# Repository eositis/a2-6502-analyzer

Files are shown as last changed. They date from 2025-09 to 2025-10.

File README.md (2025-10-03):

# a2-6502-analyzer
The A2-6502 is an adapter allowing [Dr Gusman's LogicAnalyzer](https://github.com/gusmanb/logicanalyzer) to capture all 6502 signal pins on an Apple II. This adapter is spefically designed for the Apple IIc, but work equally well in the Apple IIe. It will work in the older Apple II and II+, however extra spacers are required, as the expansion slots get in the way.

In the Apple IIc, the adapter fits into the motherboard's CPU socket, even with the motherboard still in the case. No other components are obstructed, giving the user complete access to all available signals on the board. In an Apple IIe, the adapter's layout also allows access to all signals on the system. It does however block the use of slots 3 and 4.



The adapter board maps the Apple IIc 6502 signals to specific ports on the LogicAnalyzer pair. An additional 16 ports are available on an expansion header, allowing the user to not only capture cpu specific signals, but to also reach out to additional areas of the system to gather related information.

Dr Gusman's 6.5 release is recommended for this deployment. At this time, it is still in beta. This release provides profile support, and allows the user to import a port assignment set when using the a2-6502 adapter. A basic profile for this board is available [here](https://github.com/eositis/a2-6502-analyzer/tree/main/Gusmans-LogicAnalyzer).
1. profiles.json
   - MacOS and Linux users copy the file to $HOME/Library/Application Support/LogicAnalyzer
   - Windoze users copy the file to %userprofile%/appdata/roaming/logicanalyzer
   - if you already have a pofile created, you will need to copy the relevant data into your existing profile

## Initial Setup
1) Install firmware to LogicAnalyzer
2) Install two LogicAnalyzer boards to the adapter with the component side facing the cpu
3) Using three DuPont cables, connect the linking headers between the two boards. Does not matter which ports combination is used, as long as top is to top, middle to middle and bottom to bottom.
   - LogicAnalyzers purchased from me will be configured to snap together, eliminating this step.
4) Remve the cpu from the system board, and install it in the provided space on the adapter board. Be sure to maintain the correct notch orientation.
   - Optionally, install a spare CPU in the adapter board, leaving it there permanently. Set aside the system's CPU for the duration of the tests.
6) Carefully plug the adapter board into the cpu socket on the mother board - once again, take care to maintain correct notch orientation. Make sure the adapter is fully seated in the socket.
   - Some older sockets may not have sufficiently large holes for the logic analyzer's pins. If this is the case, install a doublewipe cpu socket to the motherboard and plug the logic analyzer adapter board into the doublewipe socket.
8) Download and configure the LogicAnalyzer software
   - Stable release here: https://github.com/gusmanb/logicanalyzer/releases
   - 6.5 beta realease information is here: https://github.com/gusmanb/logicanalyzer/discussions/277
10) follow install and operation guidelines in the [LogicAnalyzer wiki](https://github.com/gusmanb/logicanalyzer/wiki/06---The-LogicAnalyzer-program)

### Setup LogicAnalyzer boards using USB
1) Two USB cables will be needed
2) On the adapter board, set the jumper/switch to USB mode.
   - WiFi mode should only be used when the LogicAnalyzer has been configured for Network operation running in full wireless mode.
3) On each LogicAnalyzer board is a switch to set reference voltage
   - Typically should be set to EXT mode. This will use the Apple II system's 5v rail as a reference
   - The 5V reference can also be used. This mode can be used if testing Apple II power-on procedures. Testers have suggested that the LogicAnalyzer should start up faster than the Apple II, however this has not been confirmed.
4) Install firmware
   - extract the firmware appropriate for the Pico board installed on the LogicAnalyzers. This firmware is a part of the comprehensive download performed in an earlier step
   - each Pico board has a small reset button. Hold down this button wile plugging in one of the USB cables. Repeat for the other board.
   - on your computer, two new USB volumes will appear. Copy the appropriate firmware to the storage volume. Immediately once the copy completes, the volume will disconnect from your computer and the LogicAnalyzer will reset and boot the new firmware.
5) Configure for use
   - Start the LogicAnalyzer software
   - connect USB cables to each of the logic analyzers
   - Configure a MultiDevice scanner
   - Click 'open device'
   - Select one of the LogicAnalyzer boards as master
   - Add the second one as slave, Accept
   - Execute a data capture from an Apple II machine, do add signals via the J3 port at this time
   - Channels up to  32 should have data. Channels 33-48 should be blank lines. If this is not the case, close the device and recreate it, placing the other LogicAnalyzer as master.
   - From the profiles menu, select the previously imported Apple II profile
6) Congratulations! Setup is complete!

## Channel assignments
| J1-Analyzer1 | Signal | Pin | J2-Analyzer2 | Signal |
|---:|---|---|---:|---|
| CH-1 | RDY | 1 | CH-25 | A8 |
| CH-2 | IRQ\ | 2 | CH-26 | A9 |
| CH-3 | NMI\ | 3 | CH-27 | A10 |
| CH-4 | R/W\ | 4 | CH-28 | A11 |
| CH-5 | PHASE0 | 5 | CH-29 | A12 |
| CH-6 | RES\ | 6 | CH-30 | A13 |
| CH-7 | D0 | 7 | CH-31 | A14 |
| CH-8 | D1 | 8 | CH-32 | A15 |
| CH-9 | D2 | 9 | CH-33 | J3-1 |
| CH-10 | D3 | 10 | CH-34 | J3-2 |
| CH-11 | D4 | 11 | CH-35 | J3-3 |
| CH-12 | D5 | 12 | CH-36 | J3-4 |
| CH-13 | D6 | 21 | CH-37 | J3-5 |
| CH-14 | D7 | 22 | CH-38 | J3-6 |
| CH-15 | A1 | 23 | CH-39 | J3-7 |
| CH-16 | A2 | 24 | CH-40 | J3-8 |
| CH-17 | A3 | 25 | CH-41 | J3-9 |
| CH-18 | A4 | 26 | CH-42 | J3-10 |
| CH-19 | A5 | 27 | CH-43 | J3-11 |
| CH-20 | A6 | 28 | CH-44 | J3-12 |
| CH-21 | A7 | 29 | CH-45 | J3-13 |
| CH-22 | A8 | 30 | CH-46 | J3-14 |
| CH-23 | Phase1 | 32 | CH-47 | J3-15 |
| CH-24 | SYNC | 32 | CH-48 | J3-16 |

## J3 header pin assignments
The Opt X.nn signals are routed to the J3 breakout header. The user can use standard DuPont cables and clips to reach out to other parts of the system for additional data.
The J3 header signals are ordered as follows:

| PIN-1 | PIN-3 | PIN-5 | PIN-7 | PIN-9 | PIN-11 | PIN-13 | PIN-15 |
|:-----:|:-----:|:-----:|:-----:|:-----:|:-----:|:-----:|:-----:|
| CH-33 | CH-35 | CH-37 | CH-39 | CH-41 | CH-43 | CH-45 | CH-47 |
| CH-34 | CH-36 | CH-38 | CH-40 | CH-42 | CH-44 | CH-46 | CH-48 |
| PIN-2 | PIN-4 | PIN-6 | PIN-8 | PIN-10 | PIN-12 | PIN-14 | PIN-16 |

## Schematics
Production v1.5 schematic: https://github.com/eositis/a2-6502-analyzer/blob/main/kicad/v1.5/6502-interposer-schematic-1_5.pdf

### Board View
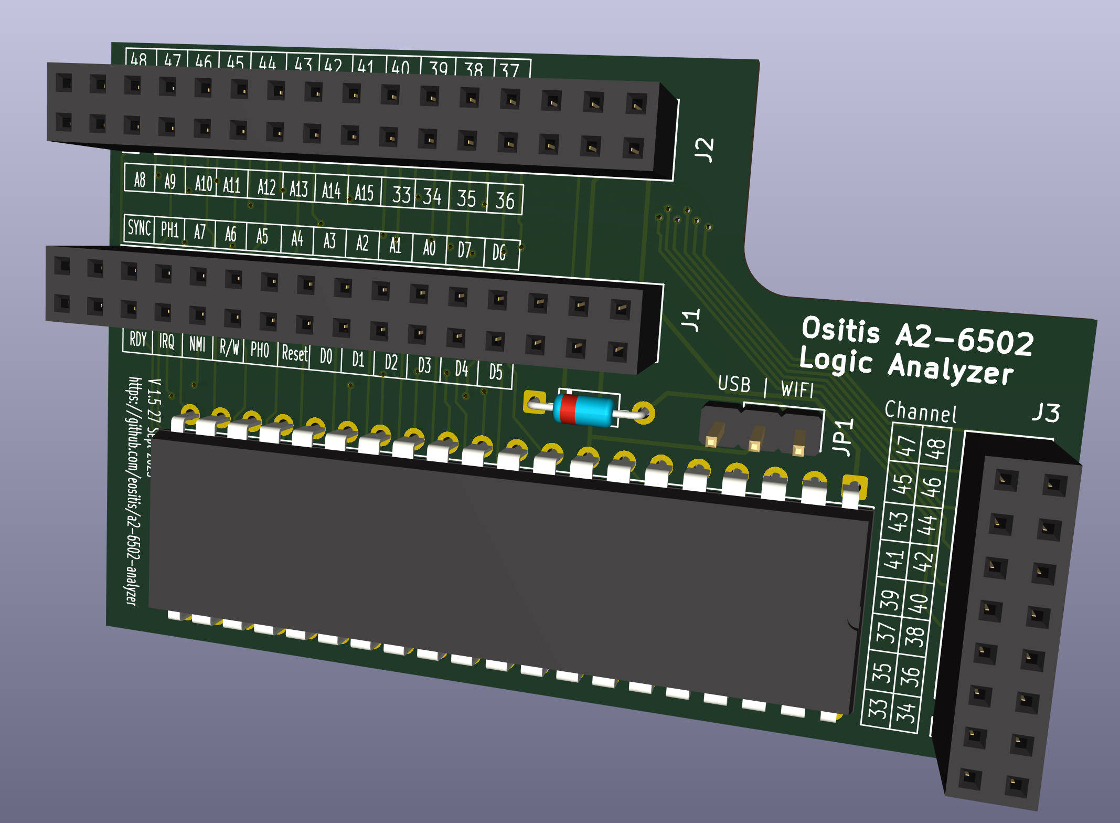
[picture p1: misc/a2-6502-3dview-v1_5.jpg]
a2-6502-v1 5


### Ready to collect data
a2-6502-action-v1_4

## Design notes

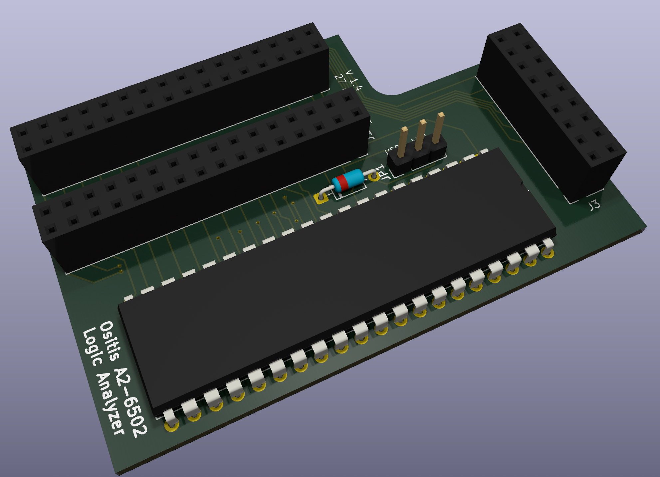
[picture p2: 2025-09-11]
a2-6502v14.jpg

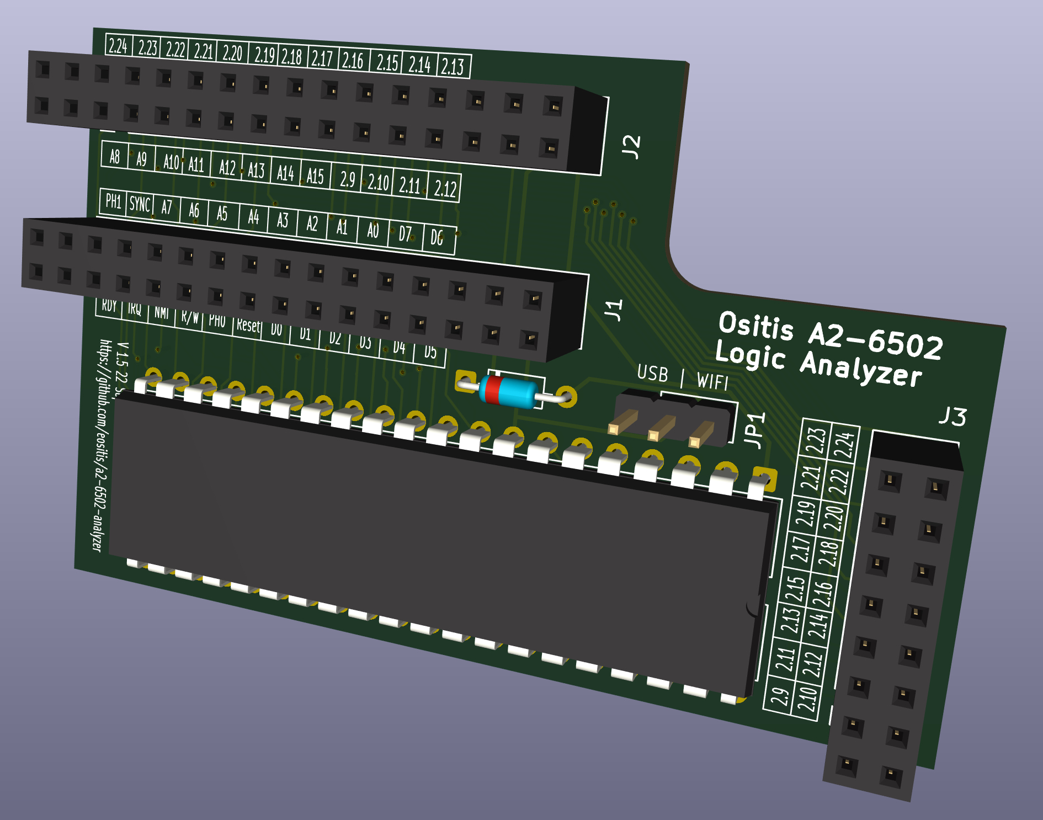
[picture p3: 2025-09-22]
a2-6502-v1.5.jpg

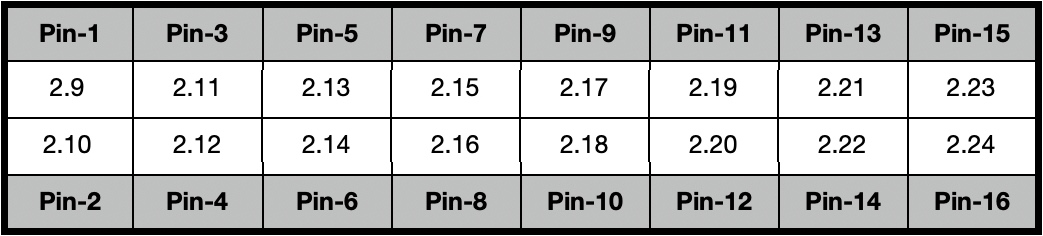
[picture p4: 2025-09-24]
misc/a2-6502-J3header.jpg

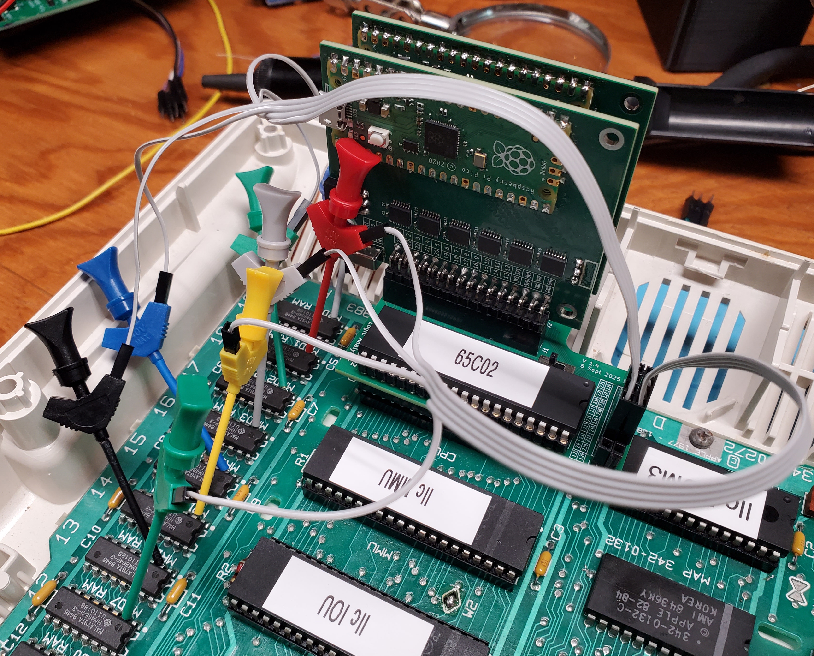
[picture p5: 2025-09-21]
misc/a2-6502-action-v1_4.jpg

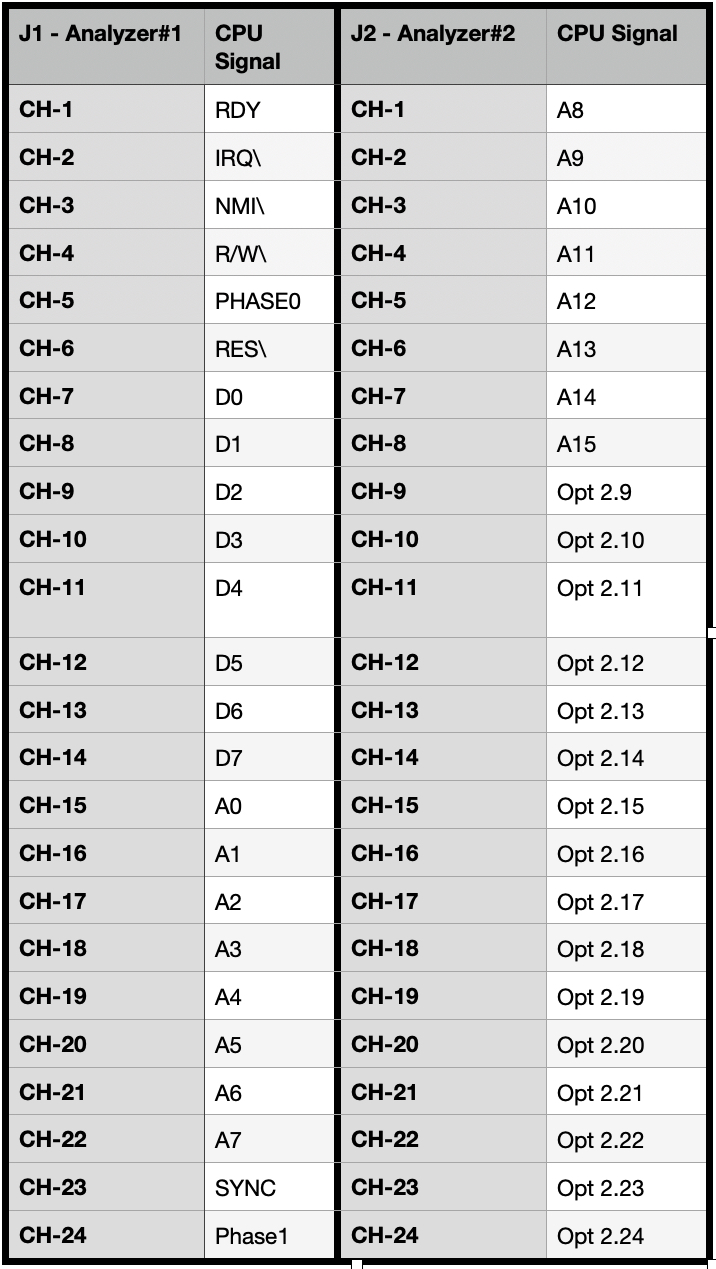
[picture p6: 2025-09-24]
misc/signal-assignments.jpg

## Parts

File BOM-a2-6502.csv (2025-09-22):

Table 1
Designator | Qty | Description | Part number | Mfg | Digikey Part Number | Notes
J1,J2 | 2 | CONN HDR 36POS 0.1 TIN PCB | PPTC182LFBN-RC | Sullins Connector Solutions | S7086-ND
J3 | 1 | CONN HDR 16POS 0.1 TIN PCB | PPTC082LFBN-RC | Sullins Connector Solutions | S7076-ND
JP1 | 1 | CONN HEADER VERT 3POS 2.54MM | HTSW-103-07-T-S | Samtec Inc. | SAM9525-ND
JP1 | 1 | CONN JUMPER SHORTING GOLD FLASH | SPC02SYAN | Sullins Connector Solutions | S9001-ND
U1 | 1 | CONN IC DIP SOCKET 40POS | AR 40-HZL-TT | Assmann WSW | 123-AR40-HZL-TT-ND
U1 | 1 | CONN RCPT 20POS 0.1 GOLD PCB | 324-43-120-41-002000 | Mill-Max Manufacturing Corp. | 324-43-120-41-002000-ND | alternate 11.75mm item from https://www.aliexpress.us/item/3256803132204291.html
D1 | 1 | DIODE STANDARD 100V 200MA DO35 | 1N4148 | onsemi | 1N4148FS-ND

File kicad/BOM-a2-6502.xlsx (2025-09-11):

Table 1
Designator | Qty | Description | Part number | Mfg | Digikey Part Number | Notes
J1,J2 | 2 | CONN HDR 36POS 0.1 TIN PCB | PPTC182LFBN-RC (https://www.digikey.com/en/products/detail/sullins-connector-solutions/PPTC182LFBN-RC/810224) | Sullins Connector Solutions | S7086-ND
J3 | 1 | CONN HDR 18POS 0.1 TIN PCB | PPTC092LFBN-RC (https://www.digikey.com/en/products/detail/sullins-connector-solutions/PPTC092LFBN-RC/810215) | Sullins Connector Solutions | S7077-ND
JP1 | 1 | CONN HEADER VERT 3POS 2.54MM | HTSW-103-07-T-S (https://www.digikey.com/en/products/detail/samtec-inc/HTSW-103-07-T-S/6678262) | Samtec Inc. | SAM9525-ND
JP1 | 1 | CONN JUMPER SHORTING GOLD FLASH | SPC02SYAN (https://www.digikey.com/en/products/detail/sullins-connector-solutions/SPC02SYAN/76375) | Sullins Connector Solutions | S9001-ND
U1 | 1 | CONN IC DIP SOCKET 40POS | AR 40-HZL-TT | Assmann WSW | 123-AR40-HZL-TT-ND
U1 | 1 | CONN RCPT 20POS 0.1 GOLD PCB | 324-43-120-41-002000 | Mill-Max Manufacturing Corp. | 324-43-120-41-002000-ND | alternate 11.75mm item from https://www.aliexpress.us/item/3256803132204291.html
D1 | 1 | DIODE STANDARD 100V 200MA DO35 | 1N4148 (https://www.digikey.com/en/products/detail/onsemi/1N4148/458603) | onsemi | 1N4148FS-ND

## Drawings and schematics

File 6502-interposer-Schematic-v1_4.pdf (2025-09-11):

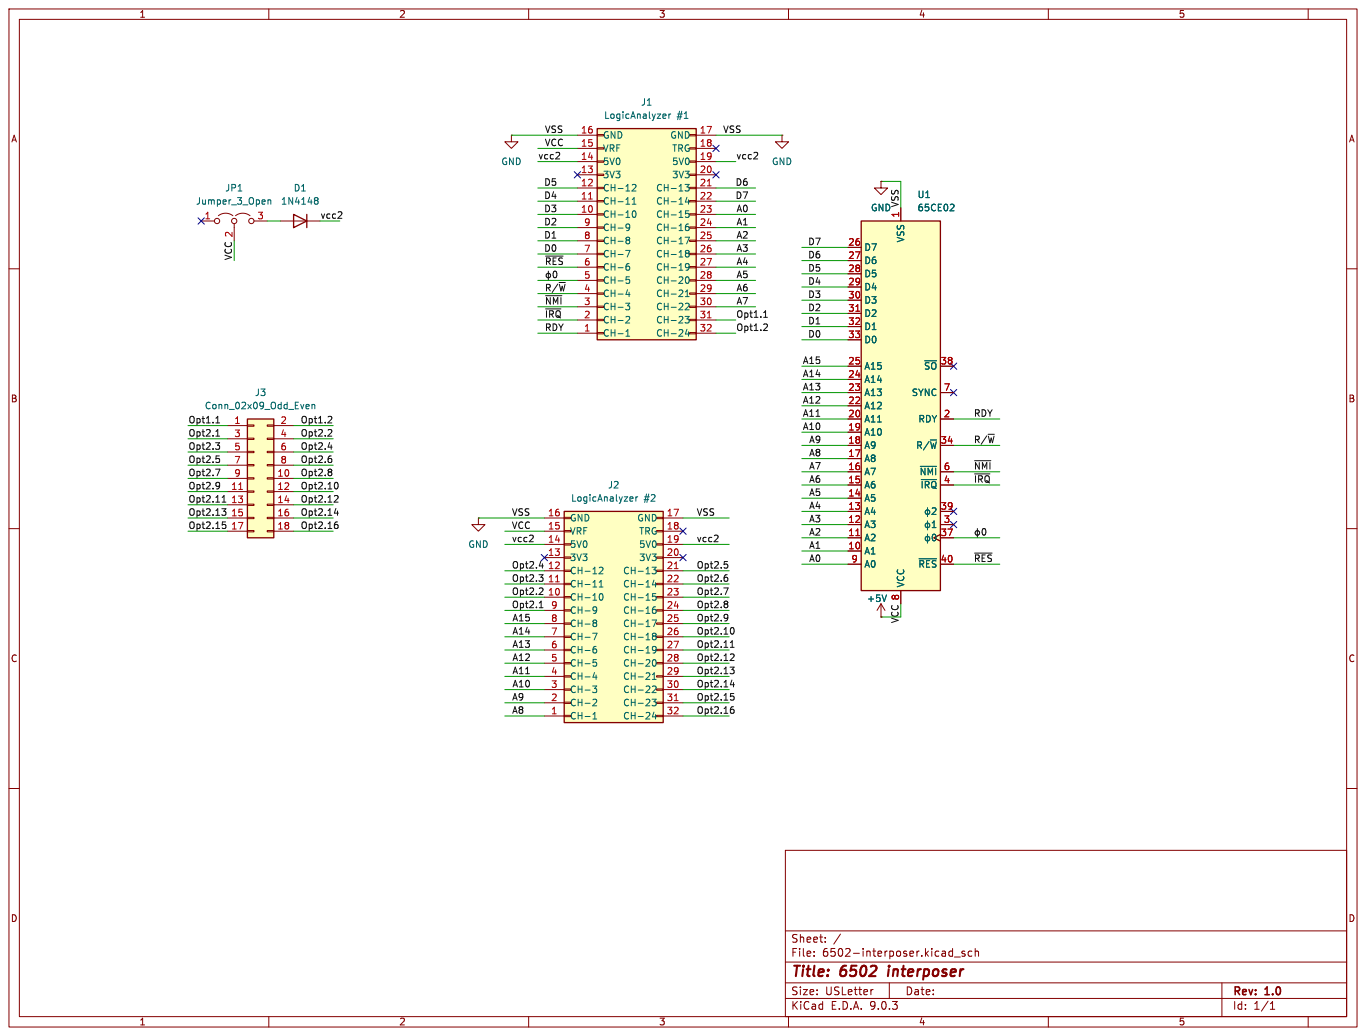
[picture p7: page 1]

Id: 1/1 Title: 6502 interposer File: 6502-interposer.kicad_sch Sheet: /

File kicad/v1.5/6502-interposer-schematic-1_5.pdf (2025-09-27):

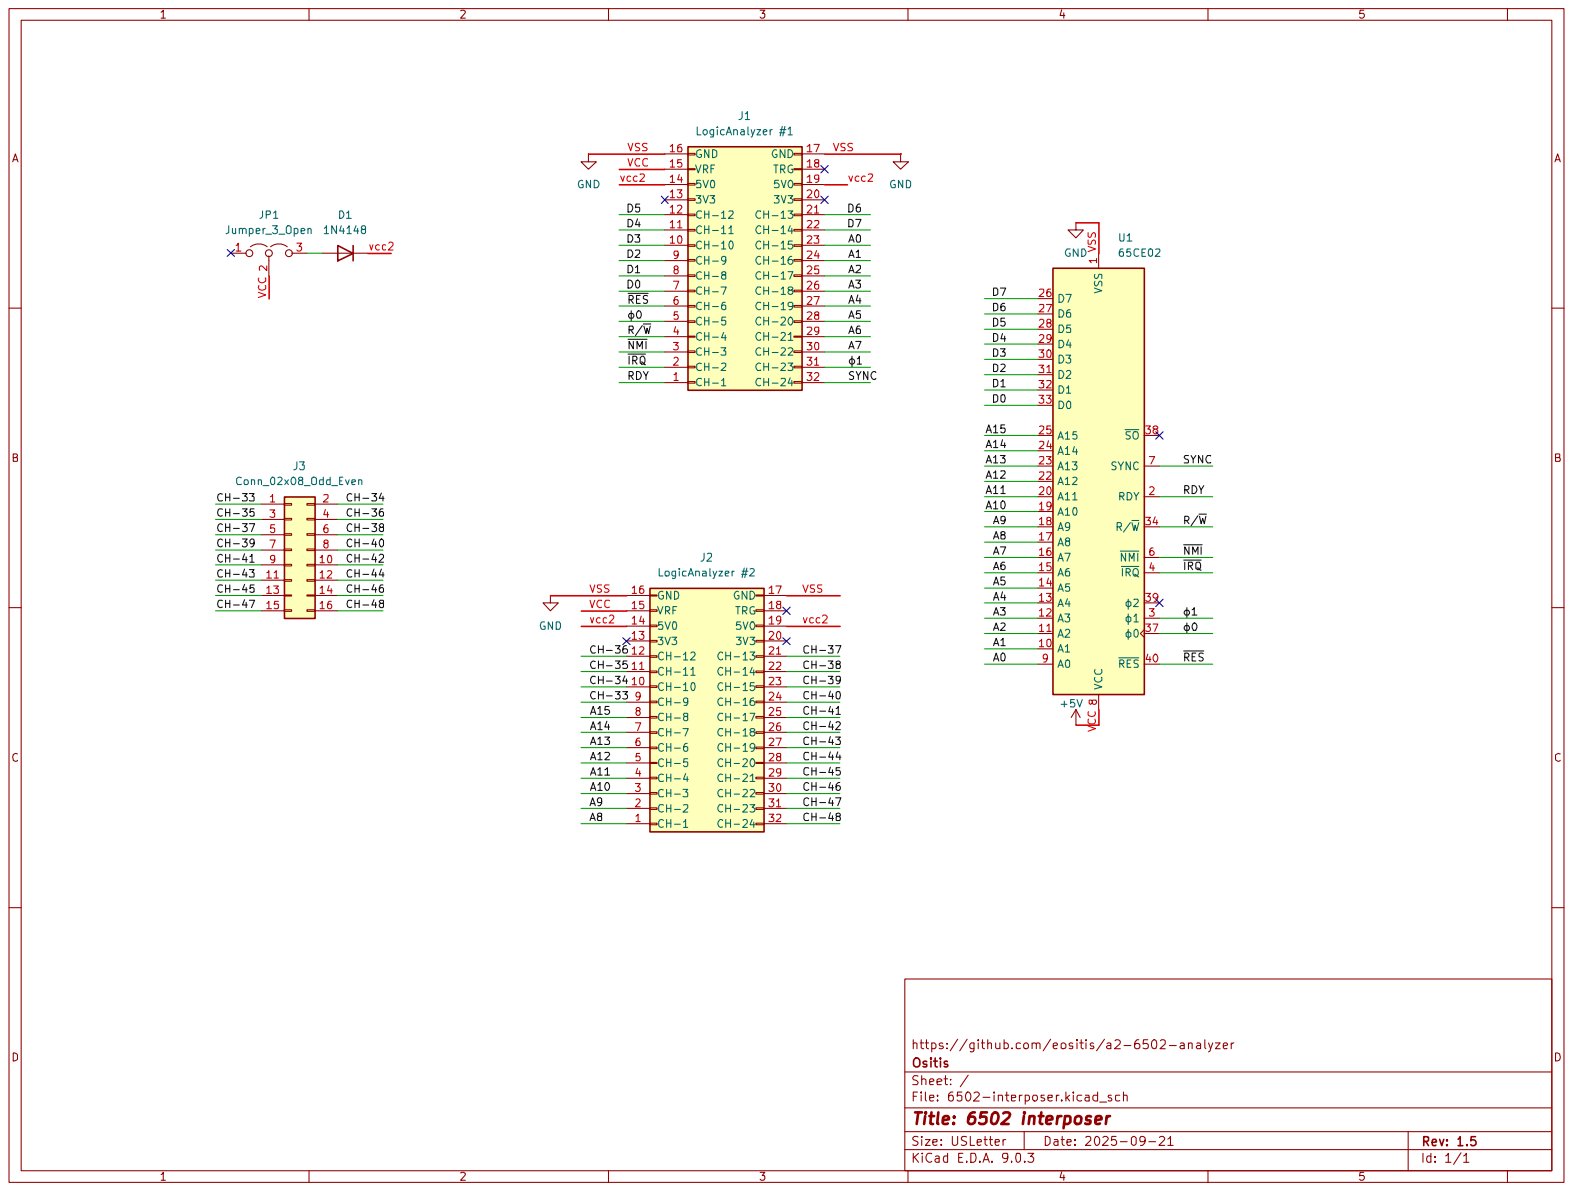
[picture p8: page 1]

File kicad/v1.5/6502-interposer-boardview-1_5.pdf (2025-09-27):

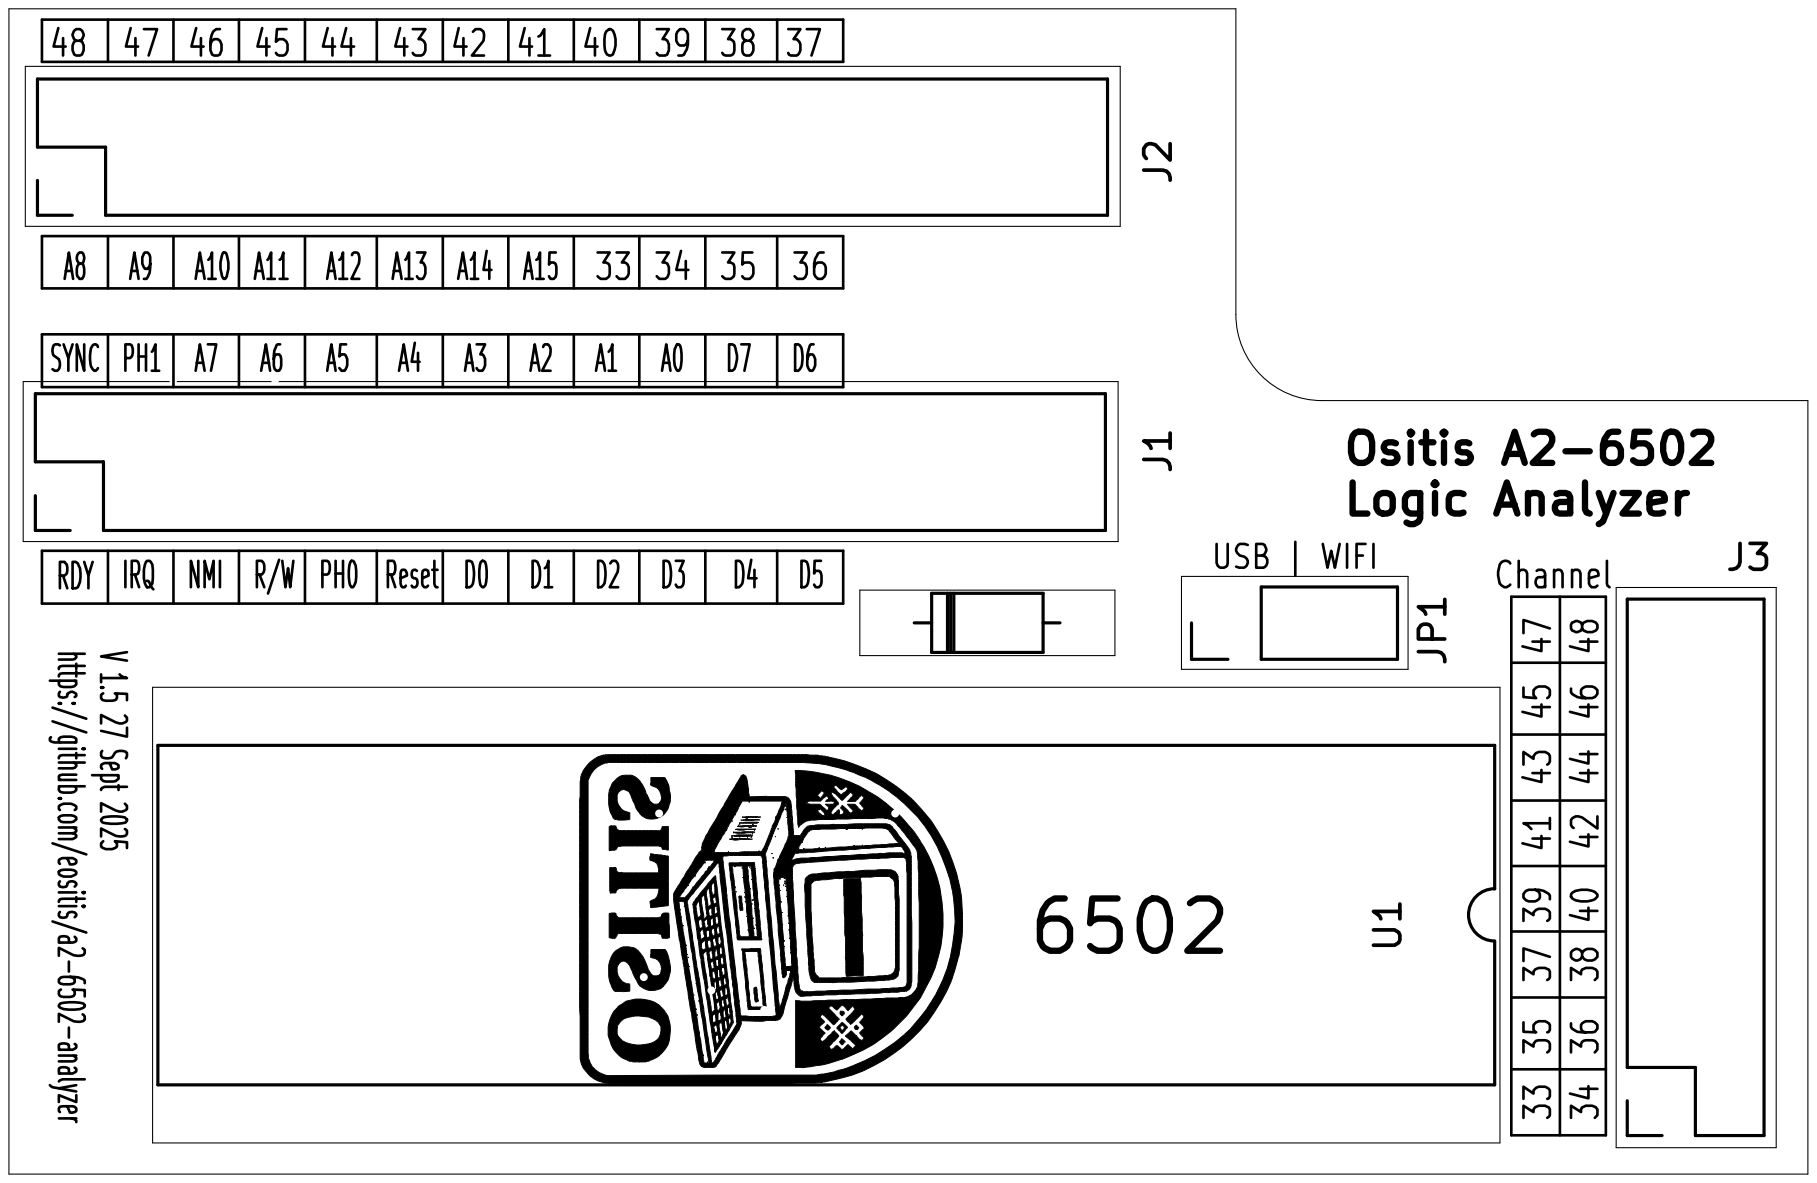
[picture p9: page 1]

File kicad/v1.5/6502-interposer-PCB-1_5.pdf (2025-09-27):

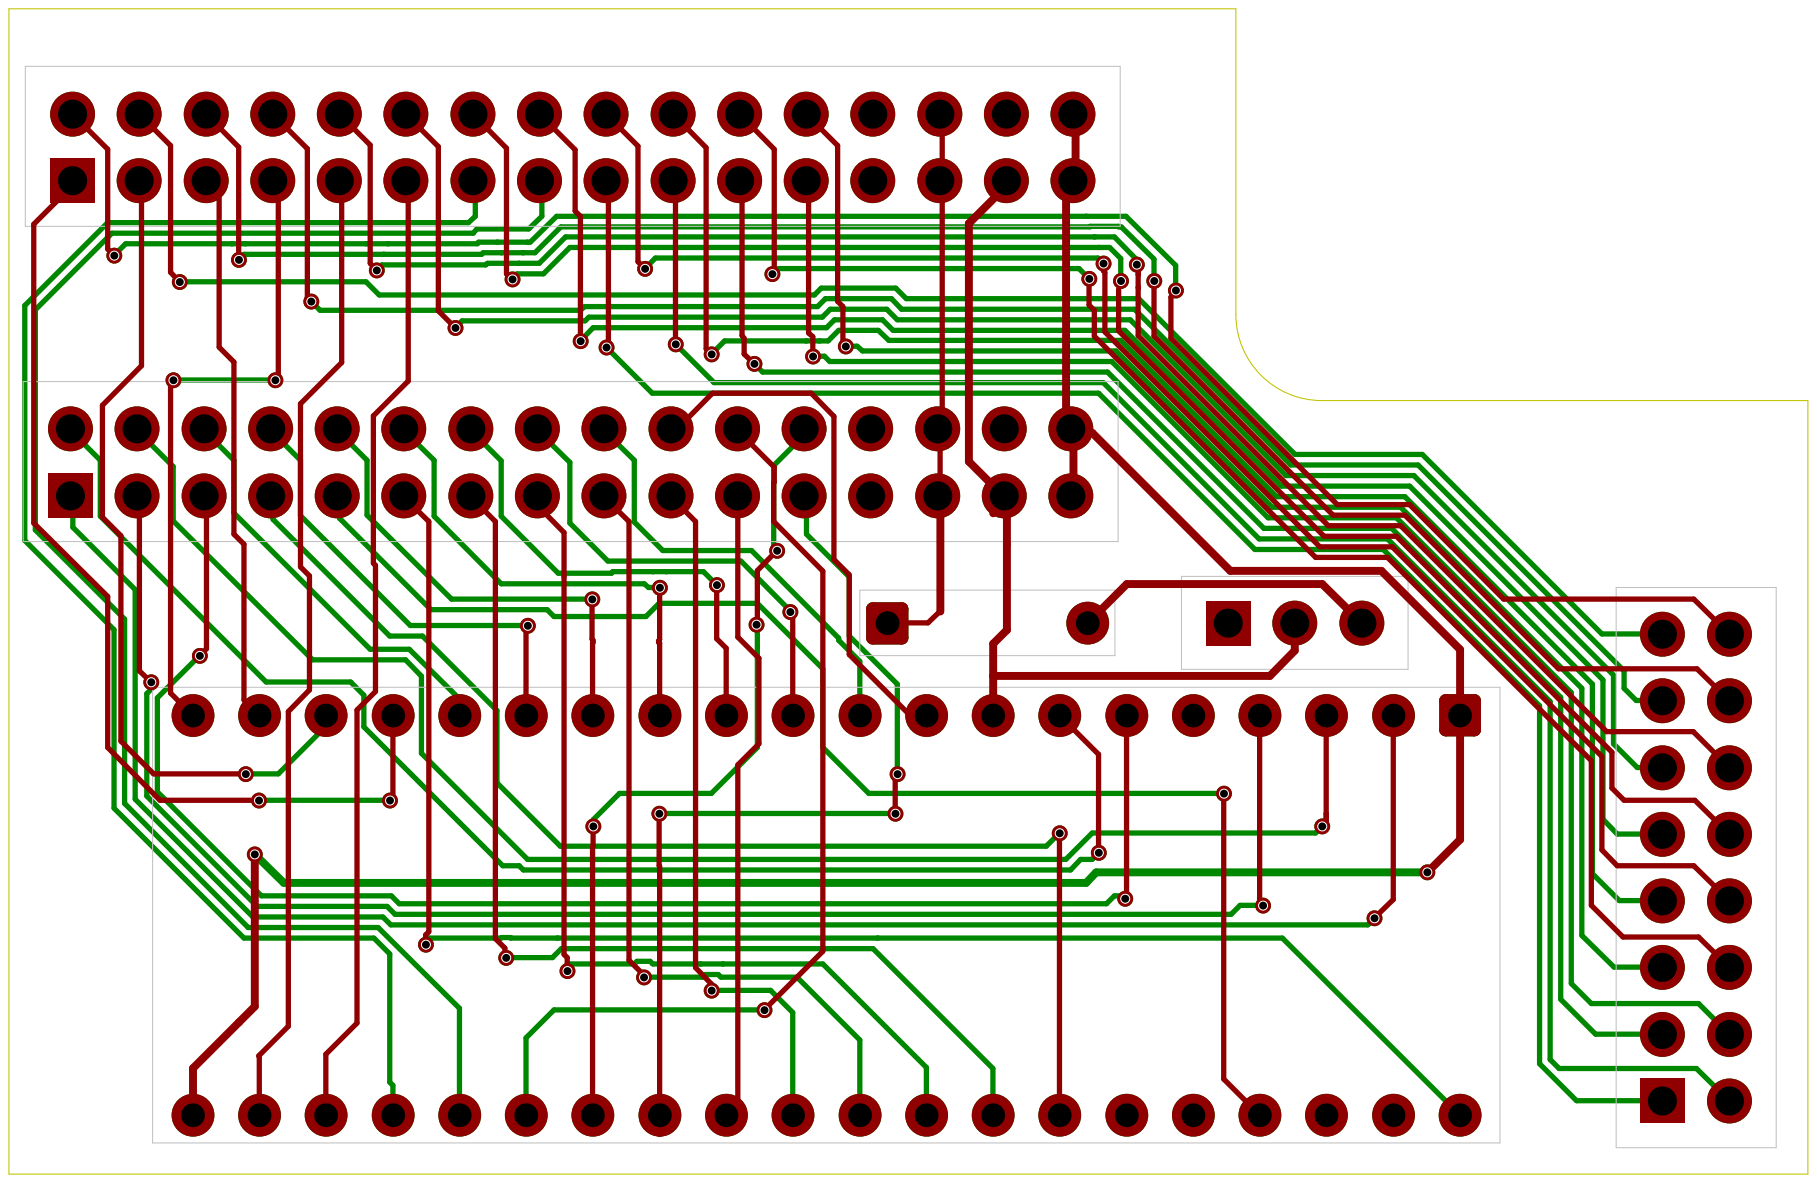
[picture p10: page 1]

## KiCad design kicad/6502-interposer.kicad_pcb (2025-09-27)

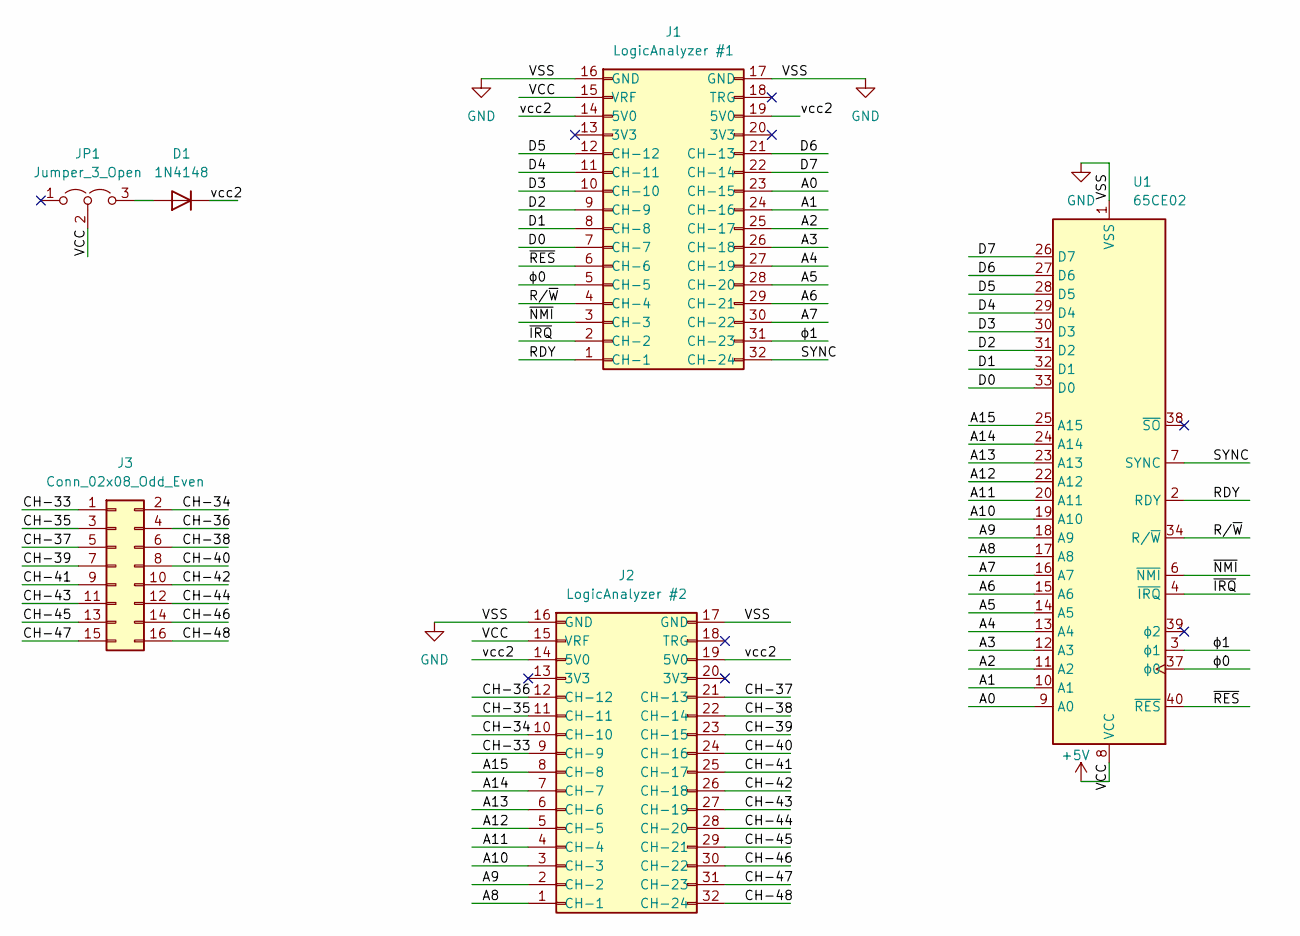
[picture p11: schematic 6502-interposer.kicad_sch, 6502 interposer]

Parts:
D1: 1N4148; D_DO-35_SOD27_P7.62mm_Horizontal
J1: LogicAnalyzer #1; PinSocket_2x16_P2.54mm_Vertical
J2: LogicAnalyzer #2; PinSocket_2x16_P2.54mm_Vertical
J3: Conn_02x08_Odd_Even; PinSocket_2x08_P2.54mm_Vertical
JP1: Jumper_3_Open; PinHeader_1x03_P2.54mm_Vertical
U1: 65CE02; DIP-40_W15.24mm

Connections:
+5V: J1.15 (VRF), J2.15 (VRF), JP1.2 (C), U1.8 (VCC)
/A0: J1.23 (CH-15), U1.9 (A0)
/A1: J1.24 (CH-16), U1.10 (A1)
/A2: J1.25 (CH-17), U1.11 (A2)
/A3: J1.26 (CH-18), U1.12 (A3)
/A4: J1.27 (CH-19), U1.13 (A4)
/A5: J1.28 (CH-20), U1.14 (A5)
/A6: J1.29 (CH-21), U1.15 (A6)
/A7: J1.30 (CH-22), U1.16 (A7)
/A8: J2.1 (CH-1), U1.17 (A8)
/A9: J2.2 (CH-2), U1.18 (A9)
/A10: J2.3 (CH-3), U1.19 (A10)
/A11: J2.4 (CH-4), U1.20 (A11)
/A12: J2.5 (CH-5), U1.22 (A12)
/A13: J2.6 (CH-6), U1.23 (A13)
/A14: J2.7 (CH-7), U1.24 (A14)
/A15: J2.8 (CH-8), U1.25 (A15)
/CH-33: J2.9 (CH-9), J3.1
/CH-34: J2.10 (CH-10), J3.2
/CH-35: J2.11 (CH-11), J3.3
/CH-36: J2.12 (CH-12), J3.4
/CH-37: J2.21 (CH-13), J3.5
/CH-38: J2.22 (CH-14), J3.6
/CH-39: J2.23 (CH-15), J3.7
/CH-40: J2.24 (CH-16), J3.8
/CH-41: J2.25 (CH-17), J3.9
/CH-42: J2.26 (CH-18), J3.10
/CH-43: J2.27 (CH-19), J3.11
/CH-44: J2.28 (CH-20), J3.12
/CH-45: J2.29 (CH-21), J3.13
/CH-46: J2.30 (CH-22), J3.14
/CH-47: J2.31 (CH-23), J3.15
/CH-48: J2.32 (CH-24), J3.16
/D0: J1.7 (CH-7), U1.33 (D0)
/D1: J1.8 (CH-8), U1.32 (D1)
/D2: J1.9 (CH-9), U1.31 (D2)
/D3: J1.10 (CH-10), U1.30 (D3)
/D4: J1.11 (CH-11), U1.29 (D4)
/D5: J1.12 (CH-12), U1.28 (D5)
/D6: J1.21 (CH-13), U1.27 (D6)
/D7: J1.22 (CH-14), U1.26 (D7)
/RDY: J1.1 (CH-1), U1.2 (RDY)
/R/~W: J1.4 (CH-4), U1.34 (R/~W)
/SYNC: J1.32 (CH-24), U1.7 (SYNC)
/vcc2: D1.1 (K), J1.14 (5V0), J1.19 (5V0), J2.14 (5V0), J2.19 (5V0)
/~IRQ: J1.2 (CH-2), U1.4 (~IRQ)
/~NMI: J1.3 (CH-3), U1.6 (~NMI)
/~RES: J1.6 (CH-6), U1.40 (~RES)
/ϕ0: J1.5 (CH-5), U1.37 (ϕ0)
/ϕ1: J1.31 (CH-23), U1.3 (ϕ1)
GND: J1.16 (GND), J1.17 (GND), J2.16 (GND), J2.17 (GND), U1.1 (VSS), U1.21 (VSS)
unnamed: D1.2 (A), JP1.3 (B)

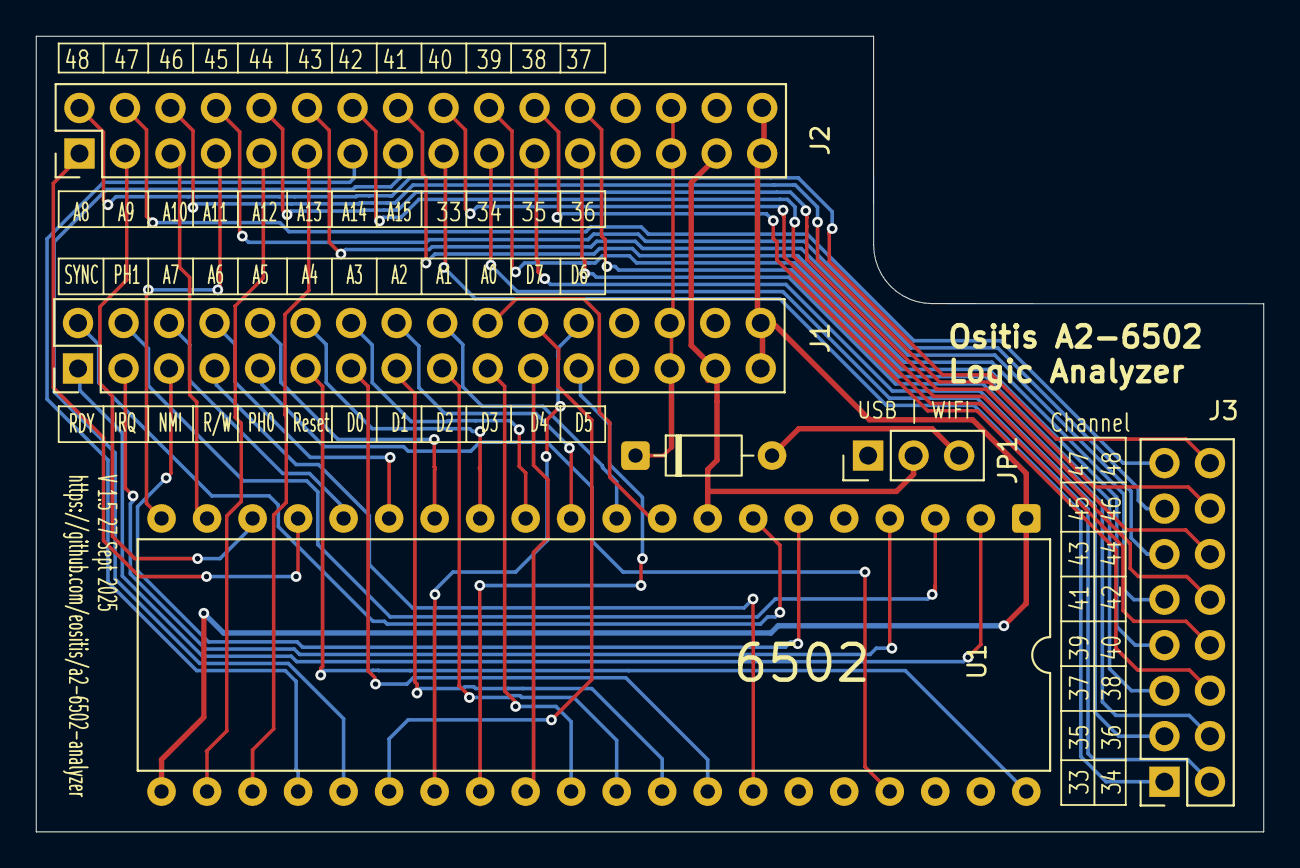
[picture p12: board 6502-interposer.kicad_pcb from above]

Board: 2 copper layers, 68.5 x 44.4 mm, 6 parts (0 on the bottom side), 52 nets.

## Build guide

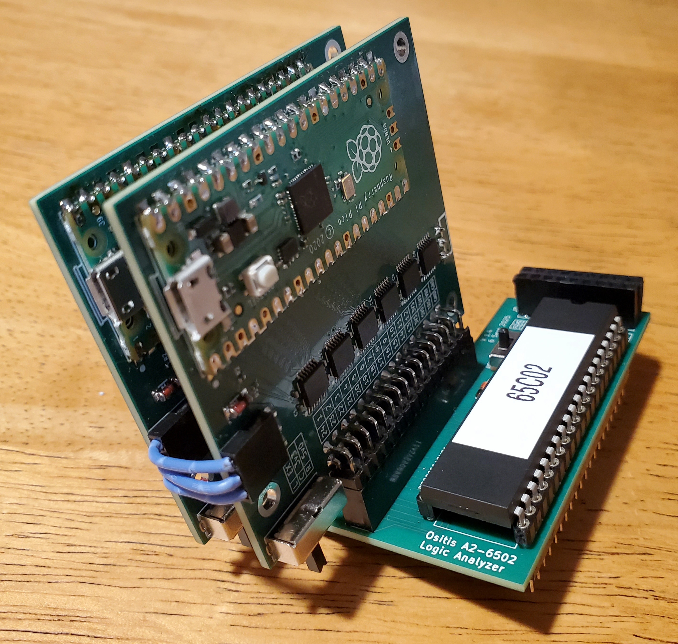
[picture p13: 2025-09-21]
misc/a2-6502-assembled-v1_4.jpg

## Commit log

2025-09-11 Initial Commit for v1.4
    [6502-interposer-B_Cu.gbr, 6502-interposer-B_Mask.gbr, 6502-interposer-B_Silkscreen.gbr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]
2025-09-11 BOM update
    [BOM-a2-6502.xlsx]
2025-09-11 BOM update2
    [BOM-a2-6502.xlsx]
2025-09-12 version 1.5
    Fix board labelling issues. Fix Numbering issues.
    [6502-interposer-B_Cu.gbr, 6502-interposer-B_Mask.gbr, 6502-interposer-B_Silkscreen.gbr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]
2025-09-19 updates for v1.5
    [6502-interposer-B_Cu.gbr, 6502-interposer-B_Mask.gbr, 6502-interposer-B_Silkscreen.gbr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]
2025-09-21 repo cleanup and 1.5 update
    cleaned up and reorganized the repository. Updated the 1.5 version to latest, hopefully production version.
    [6502-interposer-B_Cu.gbr, 6502-interposer-B_Mask.gbr, 6502-interposer-B_Silkscreen.gbr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]
2025-09-21 final cleanup
    [6502-interposer-B_Cu.gbr, 6502-interposer-B_Mask.gbr, 6502-interposer-B_Silkscreen.gbr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]
2025-09-22 Added Phase1 and SYNC
    Ended up digging into the 6502 documentation to understand why SYNC and Phase1 are important. Although the IIc and IIe do not use these signals, they do have a function. Sync tells us when the cpu is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
    [6502-interposer-B_Cu.gbr, 6502-interposer-B_Mask.gbr, 6502-interposer-B_Silkscreen.gbr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]
2025-09-24 publish errata for 1.4 revision
    bodge wires needed to enable sync and Phase1 capture. This change makes the board compatible with the mos6502 decoder in the LogicAnalyzer 6.5 release
2025-09-27 fixed labels, sync routing
    [6502-interposer-B_Cu.gbr, 6502-interposer-B_Mask.gbr, 6502-interposer-B_Silkscreen.gbr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]
